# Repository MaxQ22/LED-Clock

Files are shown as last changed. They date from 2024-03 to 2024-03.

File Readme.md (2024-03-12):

# LED Clock

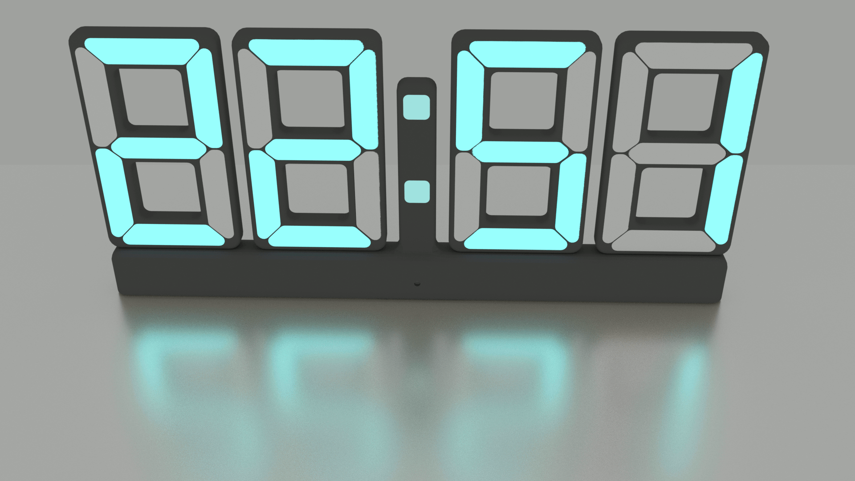
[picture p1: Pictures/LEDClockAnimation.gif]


The LED Clock uses WS2812 (NEOPixel) LEDs to emulate a seven segment clock. It is mainly intended to be used in the bedroom, to get to know the time whenever you wake up. Therefore, the clock has a "dark mode", switching the LEDs to a faint red tone, to have less impact on the sleep. The idea behind this project arose, as it is difficult by people wearing glasses, to read a common bedside clock display, when not wearing glasses at night. The LED concpet allows the display to be very big, providing better readability.

The Clock uses an ESP8266 microprocessor, programmed using the Arduino IDE to obtain the current time from a time server and subsequently driving the LEDs to show the time. The ESP8266 also reads out a light sensor to obtain the current room illumination and control the brightness of the display.

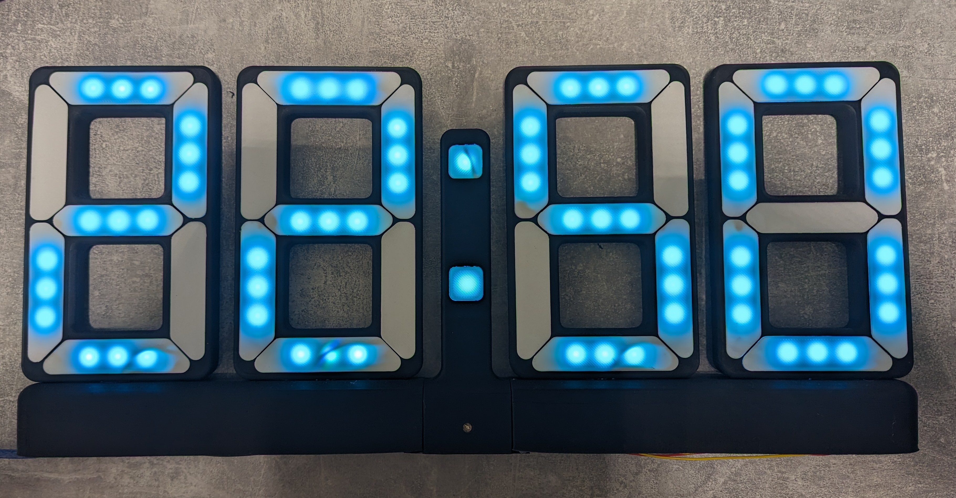
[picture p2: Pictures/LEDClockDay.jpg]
LED Clock Picture


## Build Instructions

### Bill of Materials

The housing of the clock is custom designed and intended to be 3D printed. It is designed, so that it will be printable on most hobbyist 3D printers. 

The following parts must be printed:

Quantity | Suggested Color | Part File Name 
--- | --- | ---
4 | Black | LED_Clock_Housing-DigitBackShell.stl 
4 | White | Digit_Diffusor_Set.stl
1 | Black | LED_Clock_Housing-Base Left.stl
1 | Black | LED_Clock_Housing-Base Right.stl
1 | Black | LED_Clock_Housing-Base Middle.stl

The following electronic components are needed:

Quantity | Component Name
--- | --- 
1 | ESP8266 NodeMCU Board (e.g. https://www.az-delivery.de/products/nodemcu) 
1 | 500813 Phototransistor
1 | WS2812 LED Strip (86 LEDs long)
2 | 3 Position Wago Clapms
1 | Small Piece of perfboard
1 | 10 kOhm resistor

### Digit Assembly

3D print four pices of the file LED_Clock_Housing-DigitBackShell.stl . The recommended material for the print is black PLA. Cut the WS2812 LED strip into 7 pieces of 3 LEDs each. Then glue the LED strip pieces into one of the digit back shells, as seen in the following picture. Pay particular attention to have the Di and Do solder pads in the correct position. Cut connecting cables into 30mm pieces and use them to connect the LED strip pices as in the following picture. Below, red is used for +5V, black is used for Ground and yellow is used for the signal. Pay particular attention to wire the Di/Do signal path, as this will determine the order of the LEDs.

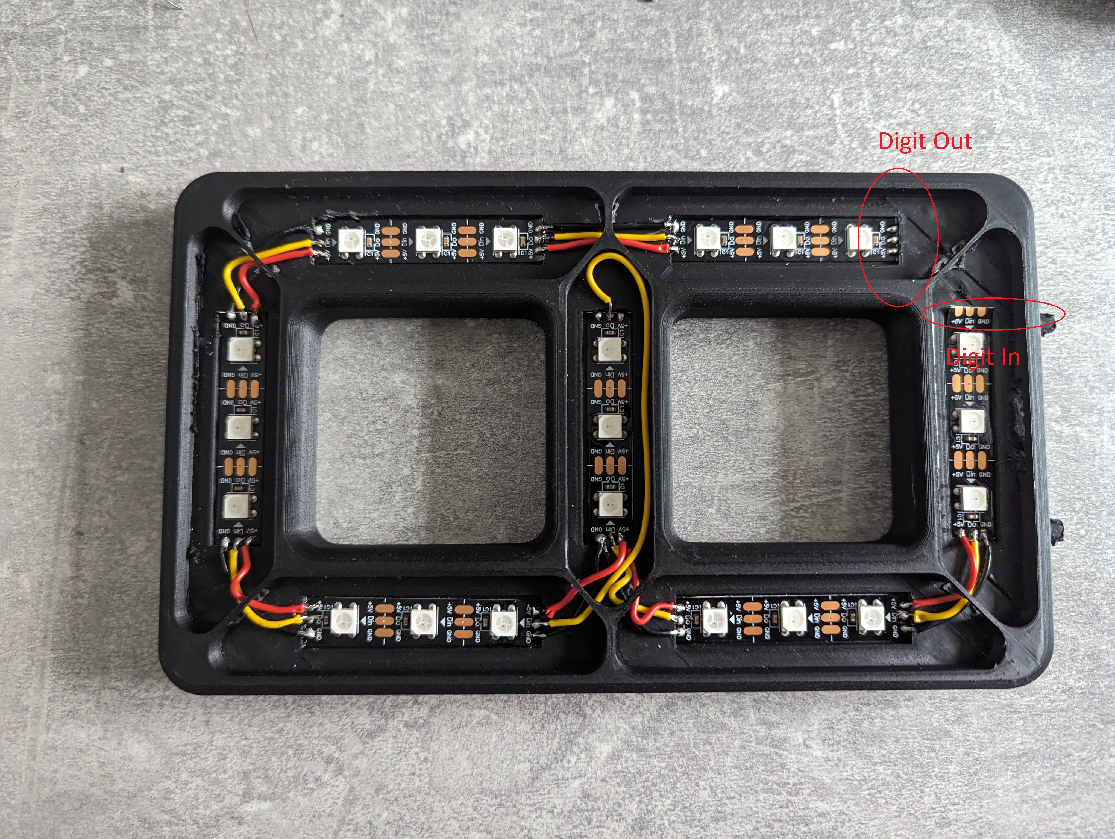
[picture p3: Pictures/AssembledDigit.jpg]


3D print four times the file Digit_Diffusor_Set.stl. The recommended material is white PLA. Print it from a full material, to avoid shine through of the infill structure in the final application.

### Light Sensor Assembly
Take a small piece of perfboard and solder the phototransistor and the 10 kOhm resistor on it. The resistor is connected to the emitter of the phototransistor. Solder three cables to the collector of the Phototransistor, the emitter of the phototransistor and the pin of the resistor, that is not connected to the phototransistor.

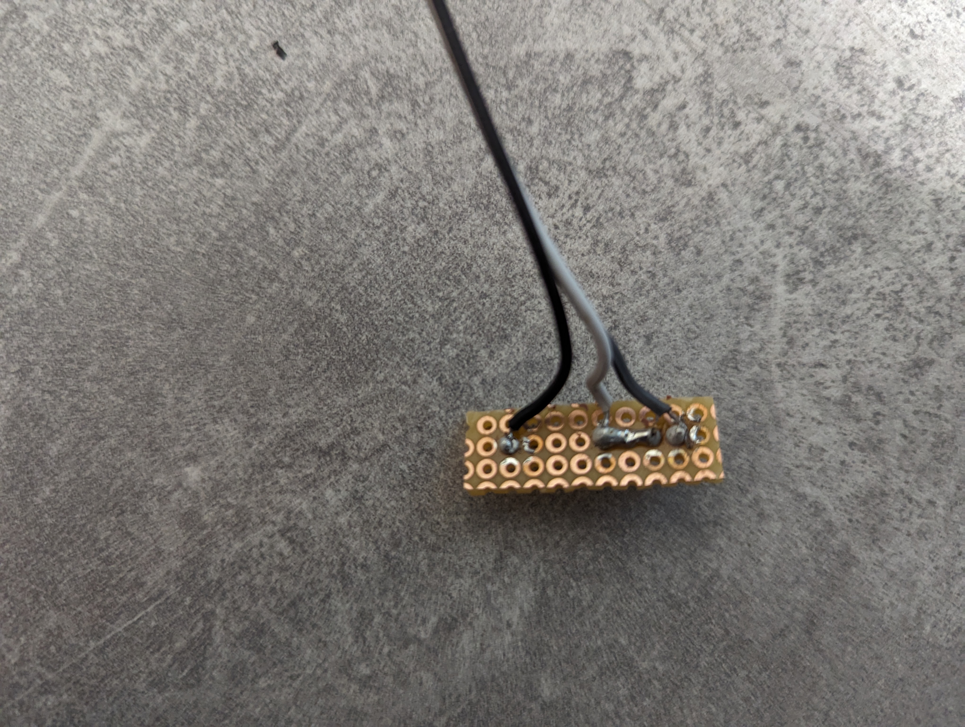
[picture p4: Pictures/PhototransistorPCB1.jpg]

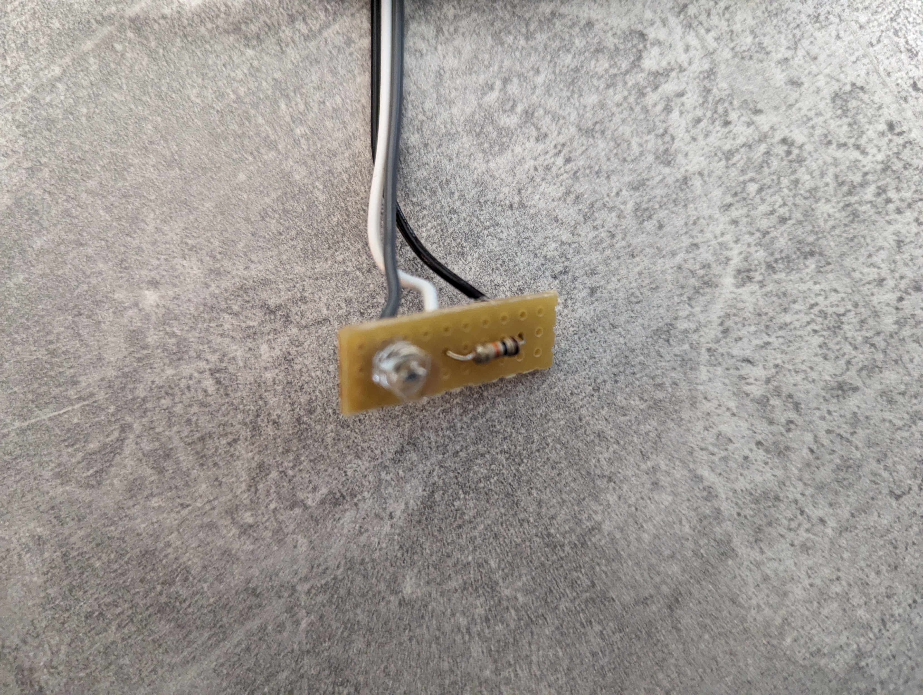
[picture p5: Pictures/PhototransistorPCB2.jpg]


### Clock Assembly
3D print one piece of the file LED_Clock_Housing-Base Left.stl. Put a bit of hot glue into the two arresting holes for the outermost digit and then put the first digit in the outer position. Take care of the orientation of the digit, with respect to the cable feedthrough on the side. The digit looks to the front, when the cable feedtrough is on the left.

Put the ESP8266 board in and connect the +5V pin of the digit in Port (as indicated in the above picture) to VIN of the NodeMCU. Connect the GND signal to ground. Connect the DIN signal of the port to pin D8 of the NodeMCU board. Feed the cable through the slit in the bottom of the digit.
Connect the Digit Out port of the leftmost digit with the Digit in port of the next digit. Connect +5V to +5V, GND to GND and DO to DI.
After soldering in the conections, put in the diffusors.

DigitPicture

Print one piece of the part LED_Clock_Housing-Base Middle.stl. Cut two LEDs from the LED strip and glue them into the two places for the dots. Take care of the orientation while doing so. Connect the +5V, GND and DO to DIN from the bottom to the top LED, as in the picture. Solder a 45 cm long cable to the DO signal of the upper LED. This will connect to the third digit later on. Solder a 35 cm long cable to the Din pin of the lower LED. This will connect to the DO signal of the Digit out port of the second digit. Solder two 10 cm long cables to the +5V and GND of the lower LED. Take two Wago clamps with three positions each and clamp the ground and +5V cable to the middle positions.

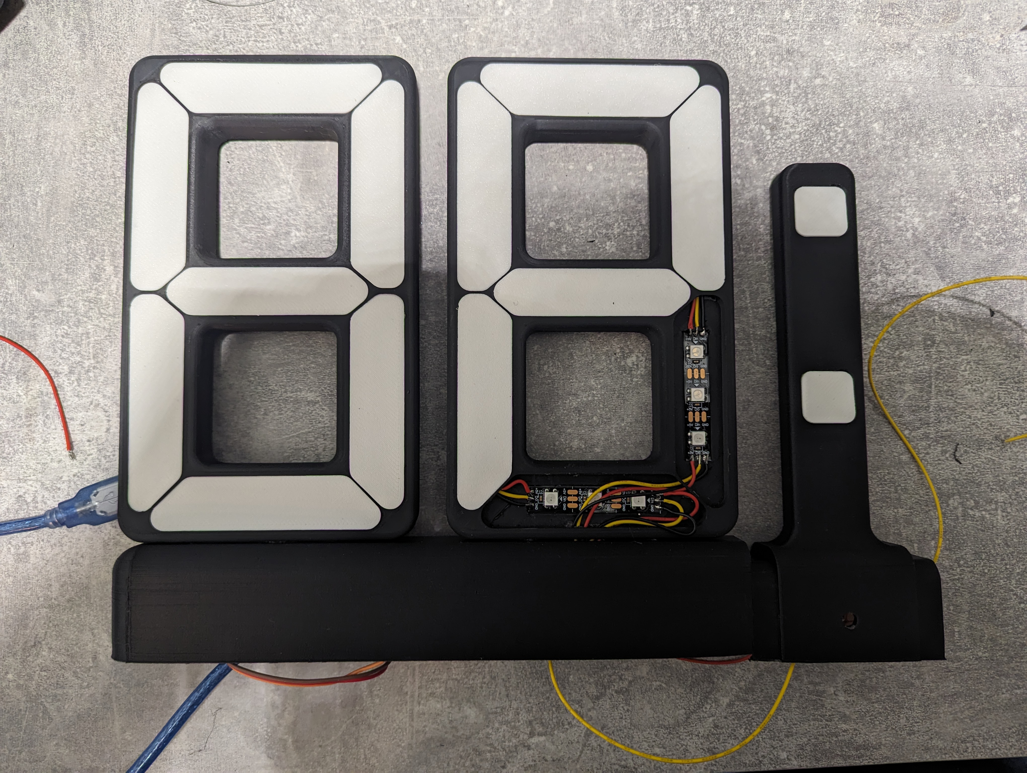
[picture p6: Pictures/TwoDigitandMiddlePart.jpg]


Glue the phototransistor PCB into the samll hole in the front of the middle part, beeing carefull, that no glue is covering the phototransistor itself. Connect the collector of the phototransistor to the +3.3V pin of the ESP8266 board, the emitter to the A0 pin and the other side of the resistor to the GND pin.

Solder two 20 cm long cables to the GND and +5V of the Digit Out port of the second digit. Connect those to the +5V and GND Wago clamps respectively.
Coat the overlapping area between the left and middle base with hot glue and glue it together.

Print one piece of the file LED_Clock_Housing-Base Right.stl. Glue the digits 3 and 4 in with a bit of hot glue. Connect the cable coming from the DO pin of the upper LED of the middle base part to the DIN of the 3rd digit. Connect the +5V and GND signals of that digits Digit In port to the respective +5V and GND Wago clamps. Connect the Digit Out port of the 3rd digit and the Digit in port of the fourth digit together, similar to the first and second digit.

After all the connections are done, secure the board and the cables with a bit of hot glue.

### Software Upload

To upload the software, open the Arduino IDE and select the NodeMCU 1.0 board. If you do not have the ESP8266 installed in the Arduino IDE, you can follow this tutorial to do so (https://randomnerdtutorials.com/how-to-install-esp8266-board-arduino-ide/). 

This software uses the Neopixel library by Adafruit to control the WS2812 LEDs. To install this library go to Tools -> Library Manager and search for the library "Adafruit NeoPixel". Install version 1.12.0 of this library.

In the file config.h, the WIFI SSID and password must be set correctly, to enable access to an NTP server on the internet. The correct time zone must also be configured. A list of time zone configurations can be accessed here: https://github.com/nayarsystems/posix_tz_db/blob/master/zones.csv.

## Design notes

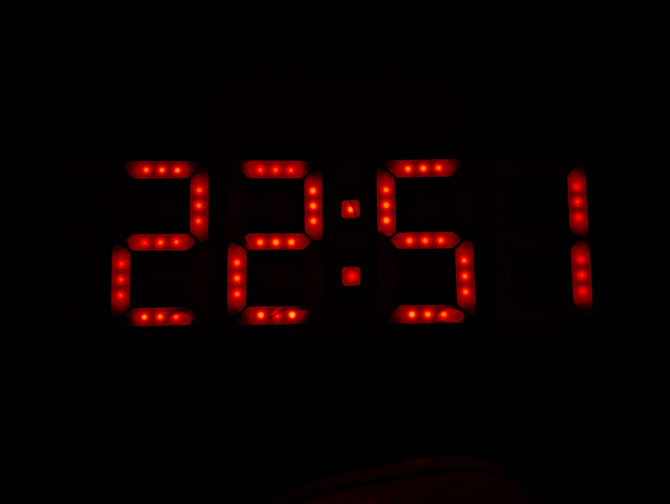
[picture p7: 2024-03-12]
Pictures/LEDClockNight.jpg

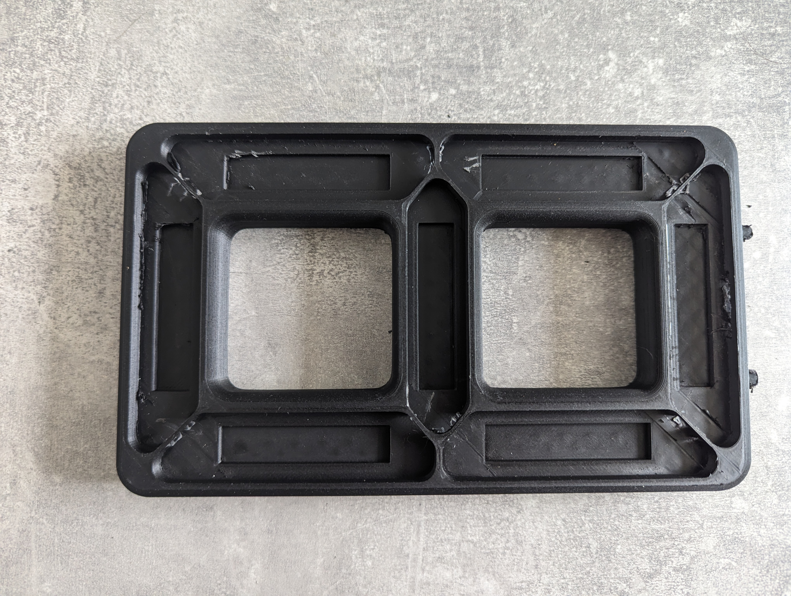
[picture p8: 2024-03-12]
Pictures/DigitBackshell.jpg

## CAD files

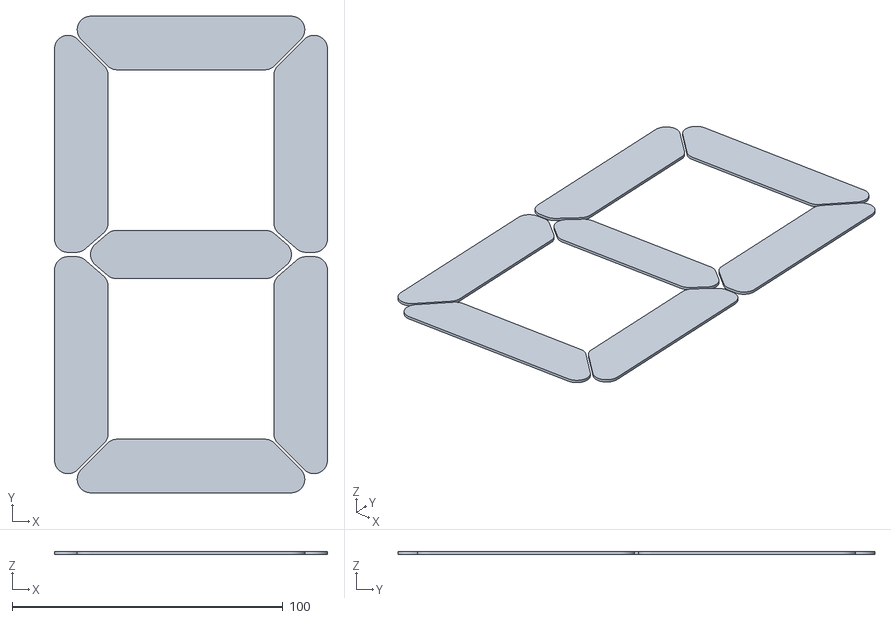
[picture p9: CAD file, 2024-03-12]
Mechanical/Digit_Diffusor_Set.stl
100.8 x 176.0 x 1.00

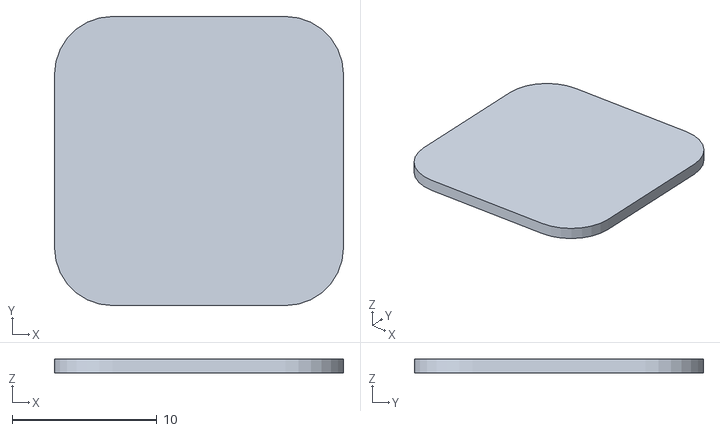
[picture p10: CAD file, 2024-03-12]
Mechanical/Dot_Diffusor.stl
20.0 x 20.0 x 1.00

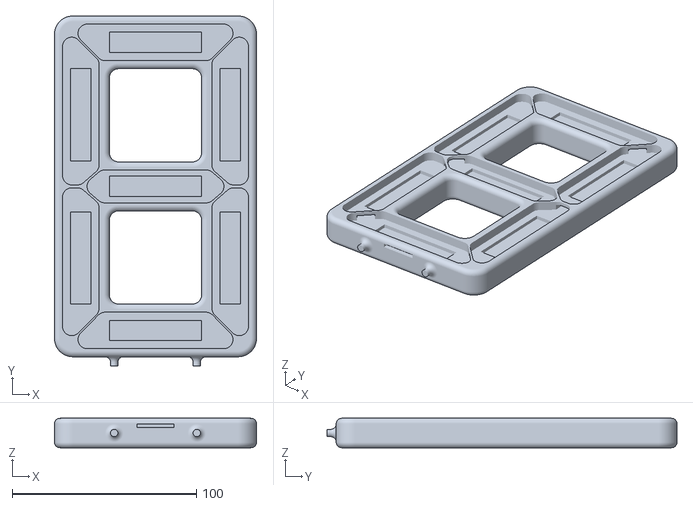
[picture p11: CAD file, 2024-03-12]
Mechanical/LED_Clock_Housing-DigitBackShell.stl
109.6 x 189.8 x 16.0

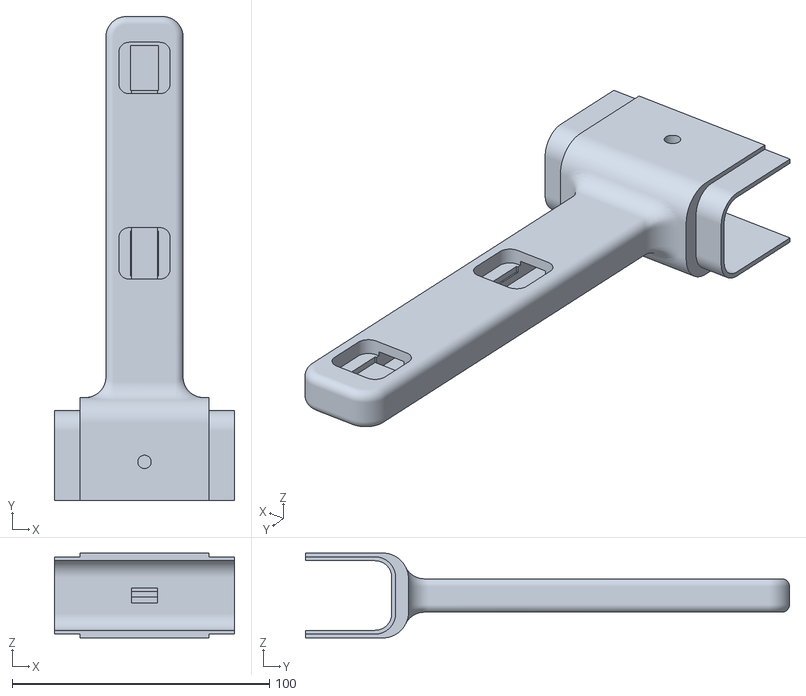
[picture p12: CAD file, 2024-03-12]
Mechanical/LED_Clock_Housing-Base Middle.stl
70.0 x 188.0 x 33.0

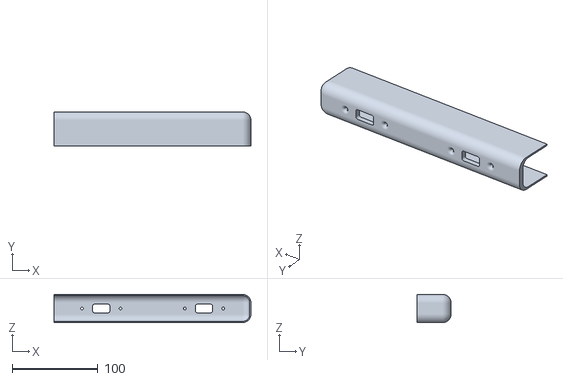
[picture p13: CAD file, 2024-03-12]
Mechanical/LED_Clock_Housing-Base Right.stl
230.0 x 40.0 x 33.0

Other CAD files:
Mechanical/LED_Clock_Housing-Base Left.stl
Animation/LED_Clock_Animation.blend

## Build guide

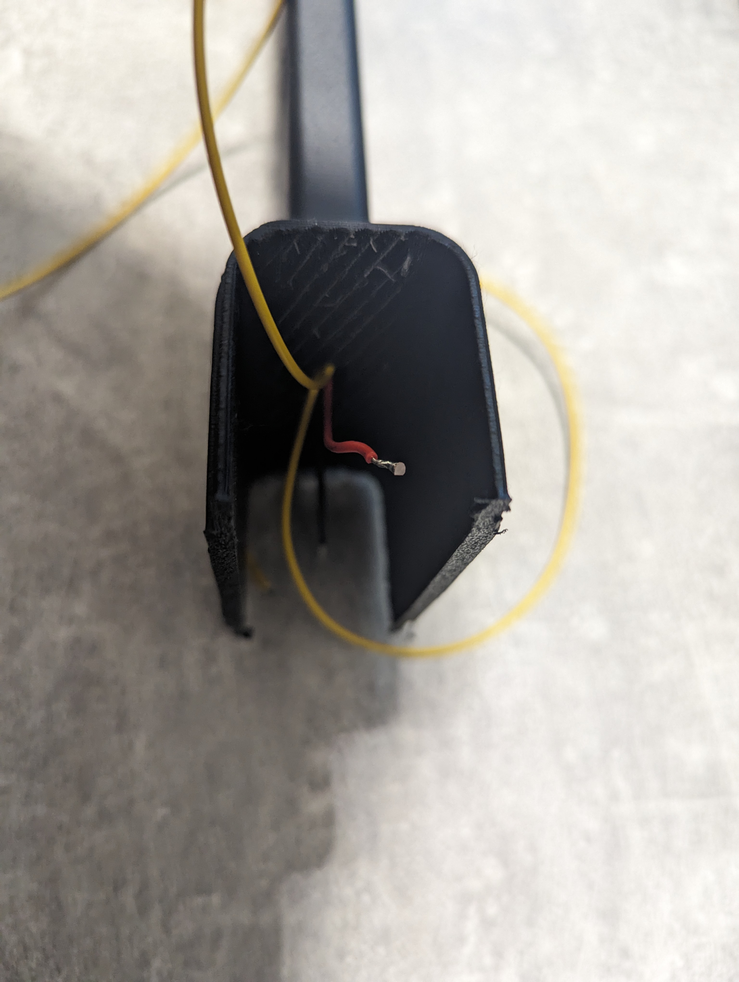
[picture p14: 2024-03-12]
Pictures/MiddlePartWiring.jpg

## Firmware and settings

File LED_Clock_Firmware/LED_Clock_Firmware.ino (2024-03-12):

//Include the Adafruit Library to control the NeoPixl LEDs
#include <Adafruit_NeoPixel.h>
//Include the Time library for timekeeping
#include <time.h>
//Include the WIFI Library for WIFI connection
#include <ESP8266WiFi.h> 

//Include the local configuration
#include "config.h"

#define PIN D8 //Pin, to which the Neopixls are connected.

#define NUMDIGITS 4 //How many digits does the clock have?
#define NUMPIXELSPERDIGIT 21 //How many Neopixl LEDs does each display have? Only multiples of 7 allowed!!!!!!
#define NUMPIXELS NUMPIXELSPERDIGIT*NUMDIGITS + 2 //Number of Neopixl in total + 2 due to the colon

//Initialize the Adadfruit Neopixl Driver
Adafruit_NeoPixel pixels(NUMPIXELS, PIN, NEO_GRB + NEO_KHZ800);

//Initialize the SSID and the Password for your local WIFI to connect to the NTP server
const char * ssid = STASSID;
const char * password = STAPSK;

//Some global variables for timekeeping
time_t current_time;
tm local_time;

void setup() 
{
  //Initialization code

  //Start the Debug connection with a Baud Rate of 115200
  Serial.begin(115200);
  Serial.println("LED Clock startup");

  //Configure the NTP server. NOTE: the NTP server will be automatically started after WIFI connection is established
  configTime(TIMEZONE, NTPSERVER);

  // Connect to wIFI
  WiFi.persistent(false);
  WiFi.mode(WIFI_STA);
  WiFi.begin(ssid, password);
  while (WiFi.status() != WL_CONNECTED) {
    delay(200);
    Serial.print ( "." );
  }
  Serial.println("\nWiFi connected");

  pixels.begin(); // Innitialize NeoPixel strip object 
}

void loop() {
  static unsigned long previousMillisColon = 0;   // Stores the last time the function was called
  static unsigned long previousMillisUpdate = 0;   // Stores the last time the function was called
  static bool colon_status = false; //Current status of the colon
  const long COLON_BLINK_INTERVAL = 2000;         // Interval in milliseconds for blinking the colon on and off(2 seconds)
  const long UPDATE_INTERVAL = 100;         // Interval in milliseconds for updating the time

   //Blink the Colon on and off 
   unsigned long currentMillis = millis();
   if (currentMillis - previousMillisColon >= COLON_BLINK_INTERVAL)
   {
    // Save the last time the function was called
    previousMillisColon = currentMillis;
    colon_status = !colon_status;
   }

   //Update the time
   currentMillis = millis();
   
   if (currentMillis - previousMillisUpdate >= UPDATE_INTERVAL)
   {
    // Save the last time the function was called
    previousMillisUpdate = currentMillis;
    time(&current_time);  //Get the current time                 
    localtime_r(&current_time, &local_time); //Convert the current timestamp to a local time struct

    //Update the Neopixls
    UpdatePixels(local_time.tm_hour * 100 + local_time.tm_min, colon_status); 
   }
}

void GeneratePixelsfromNumer(bool * p_pixels, unsigned char number)
{
  /*This is an array of bools, indicating, if the segment is on or off.
  The addresses in the array correspond to the digits as follows:

      5
    4   6
      3  
    2   7
      1
*/
  
  bool segments[7];

  //Use a look up table, to get to know, which segments are on for a given number:
  switch(number)
  {
    case 0: 
      segments[0] = 1;
      segments[1] = 1;
      segments[2] = 0;
      segments[3] = 1;
      segments[4] = 1;
      segments[5] = 1;
      segments[6] = 1;
    break;
    case 1: 
      segments[0] = 0;
      segments[1] = 0;
      segments[2] = 0;
      segments[3] = 0;
      segments[4] = 0;
      segments[5] = 1;
      segments[6] = 1;
    break;
    case 2: 
      segments[0] = 1;
      segments[1] = 1;
      segments[2] = 1;
      segments[3] = 0;
      segments[4] = 1;
      segments[5] = 1;
      segments[6] = 0;
    break;
    case 3: 
      segments[0] = 1;
      segments[1] = 0;
      segments[2] = 1;
      segments[3] = 0;
      segments[4] = 1;
      segments[5] = 1;
      segments[6] = 1;
    break;
    case 4: 
      segments[0] = 0;
      segments[1] = 0;
      segments[2] = 1;
      segments[3] = 1;
      segments[4] = 0;
      segments[5] = 1;
      segments[6] = 1;
    break;
    case 5: 
      segments[0] = 1;
      segments[1] = 0;
      segments[2] = 1;
      segments[3] = 1;
      segments[4] = 1;
      segments[5] = 0;
      segments[6] = 1;
    break;
    case 6: 
      segments[0] = 1;
      segments[1] = 1;
      segments[2] = 1;
      segments[3] = 1;
      segments[4] = 1;
      segments[5] = 0;
      segments[6] = 1;
    break;
    case 7: 
      segments[0] = 0;
      segments[1] = 0;
      segments[2] = 0;
      segments[3] = 0;
      segments[4] = 1;
      segments[5] = 1;
      segments[6] = 1;
    break;
    case 8: 
      segments[0] = 1;
      segments[1] = 1;
      segments[2] = 1;
      segments[3] = 1;
      segments[4] = 1;
      segments[5] = 1;
      segments[6] = 1;
    break;
    case 9: 
      segments[0] = 1;
      segments[1] = 0;
      segments[2] = 1;
      segments[3] = 1;
      segments[4] = 1;
      segments[5] = 1;
      segments[6] = 1;
    break;
  }

  //Each segment consists of three pixls, so convert the segment lookup table to a neopixel array
  for(unsigned int i=0; i <7; i++)
  {
  
    p_pixels[i*3] = segments[i];
    p_pixels[i*3 + 1] = segments[i];
    p_pixels[i*3 + 2] = segments[i];
  }
}

unsigned char GetLightIntensity(unsigned short adc_input, const unsigned short *adc_input_table, const unsigned char *illumination_table, size_t table_size) {
    //Get the desired light intensity of the neopixls based on the ADC -> Neopixl light intensity lookup table
    // Check if adc_input is within the range of the table
    if (adc_input <= adc_input_table[0])
    {
        // If adc_input is smaller than the smallest value in the table,
        // return the corresponding illumination value directly
        return illumination_table[0];
    } 
    else if (adc_input >= adc_input_table[table_size - 1])
    {
        // If adc_input is larger than the largest value in the table,
        // return the corresponding illumination value directly
        return illumination_table[table_size - 1];
    } 
    else
    {
        // Find the two nearest points for interpolation
        size_t idx = 0;
        while (adc_input_table[idx] < adc_input)
        {
            idx++;
        }
        // Linear interpolation
        float proportion = (float)(adc_input - adc_input_table[idx - 1]) / (adc_input_table[idx] - adc_input_table[idx - 1]);
        unsigned char estimated_illumination = (unsigned char)(illumination_table[idx - 1] + proportion * (illumination_table[idx] - illumination_table[idx - 1]));
        return estimated_illumination;
    }
}

unsigned short ADCFilter(unsigned short adc_value) {
    const float sampling_time = 0.1; // Sampling time in seconds (100 milliseconds)
    const float cutoff_frequency = 0.3; // Cutoff frequency in Hz

    // Define static variables for filter state
    static float alpha;
    static float y_prev = 0;

    // Calculate alpha using the bilinear transformation with frequency prewrapping
    float omega = 2 * 3.14159 * cutoff_frequency;
    float T = 1 / sampling_time;
    float tan_half_omega_T = 2*atanf(0.5 * omega * T);
    alpha = (tan_half_omega_T - 1) / (tan_half_omega_T + 1);

    // Apply the filter
    float y = alpha * adc_value + (1 - alpha) * y_prev;
    y_prev = y;

    return (unsigned short)y;
}

void LightIntensityFilter(unsigned char *red, unsigned char *green, unsigned char *blue, unsigned char red_stepoint, unsigned char green_stepoint, unsigned char blue_stepoint) {
    const float sampling_time = 0.1; // Sampling time in seconds (100 milliseconds)
    const float cutoff_frequency = 0.2; // Cutoff frequency in Hz

    // Define static variables for filter states
    static float alpha_red, alpha_green, alpha_blue;
    static float red_prev = 0, green_prev = 0, blue_prev = 0;

   // Calculate alpha using the bilinear transformation with frequency prewrapping
    float omega = 2 * 3.14159 * cutoff_frequency;
    float T = 1 / sampling_time;
    float tan_half_omega_T = 2*atanf(0.5 * omega * T);
    alpha_red = (tan_half_omega_T - 1) / (tan_half_omega_T + 1);
    alpha_green = alpha_red; // Use the same cutoff frequency for all channels
    alpha_blue = alpha_red; // Use the same cutoff frequency for all channels

    // Apply the filter for each color channel
    *red = alpha_red * red_stepoint + (1 - alpha_red) * red_prev;
    red_prev = *red;

    *green = alpha_green * green_stepoint + (1 - alpha_green) * green_prev;
    green_prev = *green;

    *blue = alpha_blue * blue_stepoint + (1 - alpha_blue) * blue_prev;
    blue_prev = *blue;
}

void UpdatePixels(unsigned int time_number, bool colon_status)
{
  unsigned char red = 0;
  unsigned char green = 0;
  unsigned char blue = 0;
  unsigned char light_intensity = 0;
  unsigned short adc_value = 0;
  unsigned int adc_accumulator = 0;
  const unsigned short ADC_CYCLES = 10;
  bool pixeldata[NUMPIXELSPERDIGIT * NUMDIGITS + 2];

  //Generate the Data for the digits
  GeneratePixelsfromNumer(pixeldata, time_number/1000 % 10);
  GeneratePixelsfromNumer(&pixeldata[NUMPIXELSPERDIGIT], time_number/100 % 10);
  GeneratePixelsfromNumer(&pixeldata[NUMPIXELSPERDIGIT*2 + 2], time_number/10 % 10);
  GeneratePixelsfromNumer(&pixeldata[NUMPIXELSPERDIGIT*3 + 2], time_number % 10);


   //Blink the colon 
   pixeldata[NUMPIXELSPERDIGIT * 2] = colon_status;
   pixeldata[NUMPIXELSPERDIGIT * 2 + 1] = colon_status;

  //Read the analog value of the phototransistor
  for (unsigned short n=0;n<ADC_CYCLES;n++)
  {
      adc_value = analogRead(A0);
      adc_accumulator += adc_value;
  }
  //Get the average of several ADC readings
  adc_value = adc_accumulator / ADC_CYCLES;
  adc_value = ADCFilter(adc_value);

  //Some Debug Information
  Serial.print("ADC Value: ");
  Serial.println(adc_value);
  light_intensity = GetLightIntensity(adc_value, adc_input_table, illumination_table, table_size);
  Serial.print("Light Intensity: ");
  Serial.println(light_intensity);

  //Determine if it is dark or not, to make the display red, when it is dark for better visibility 
  if(light_intensity > NIGHTTHRESHOLD)
  {
    LightIntensityFilter(&red, &green, &blue, 0, light_intensity, light_intensity);
  }
  else
  {
    LightIntensityFilter(&red, &green, &blue, light_intensity, 0, 0);
  }

  //Transfer the data to the Neopixls
  for(unsigned int i=0;i < NUMPIXELSPERDIGIT * NUMDIGITS + 2; i++)
  {
    if(pixeldata[i])
    {
        pixels.setPixelColor(i, red, green, blue);
    }
    else
    {
      pixels.setPixelColor(i, 0, 0, 0);
    }
  }
  pixels.show();
}
